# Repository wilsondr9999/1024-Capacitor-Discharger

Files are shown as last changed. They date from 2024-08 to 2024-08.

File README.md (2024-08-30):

# Capacitor Discharger

This project is a passive (unpowered) capacitor discharger that can safely discharge capacitors up to 450V and 1000 uF.  It assists the operator in quickly discharging the capacitor and providing visual feedback of the discharging process and its completion.

## Overview

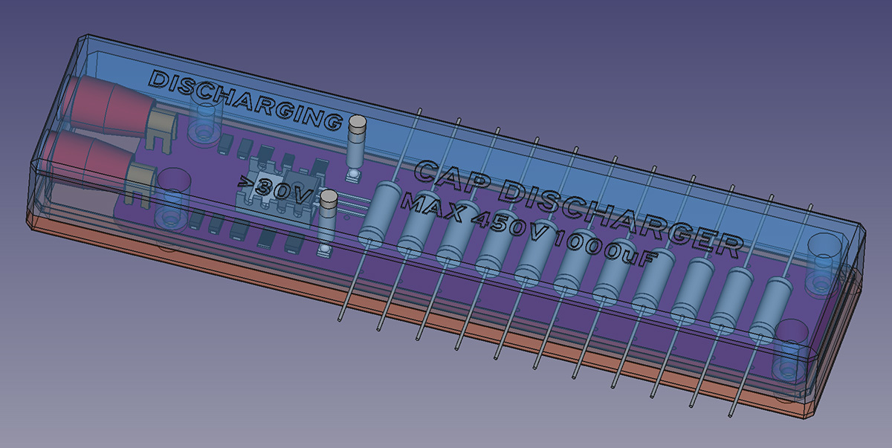
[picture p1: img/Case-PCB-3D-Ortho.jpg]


The capacitor discharger is a handheld unit with 2 LEDs for indication, and two standard shrouded test lead ports on one end.  It's purpose is to allow safe discharge of a capacitor that is in-circuit prior to working on that circuit.  Capacitors can hold a charge, sometimes for a long period of time, and in some circuits the amount of energy they can hold is dangerous, even potentially lethal.

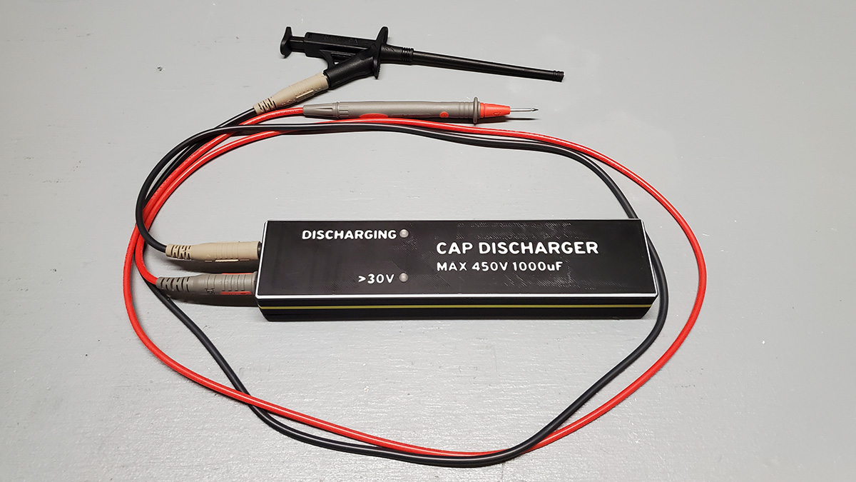
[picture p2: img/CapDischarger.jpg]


This unit allows the operator to touch two test leads to the capacitor terminals, and the unit will allow the capacitor to discharge at a constant rate of 125 mA.  This is sufficient current to discharge the largest capacitor that is recommended to be discharged with this unit (a capacitor rated up to 450V, and up to 1000 uF of capacitance) within about 15 seconds.

## Principle of Operation

The unit is a passive device, i.e. it is not powered and no batteries or power source is needed.  The energy in the capacitor is used to light the indicator LEDs during the discharge.

A fixed resistance bank is used to allow the capacitor to discharge at a constant current of 125 mA.  The capacitor's energy is dumped into 11 resistors rated at 5W each.

One LED (yellow) lights as the capacitor is discharging.  This LED will remain lit until the capacitor has no more energy (usually when it's voltage is less than 2V).

The other LED (red) lights if the capacitor voltage is above 30V.  This LED will extinguish when the capacitor has discharged to less than 30V, indicating that the capacitor would be safe to touch.  An IGBT transistor is used in a specific configuration to drive the >30V LED.

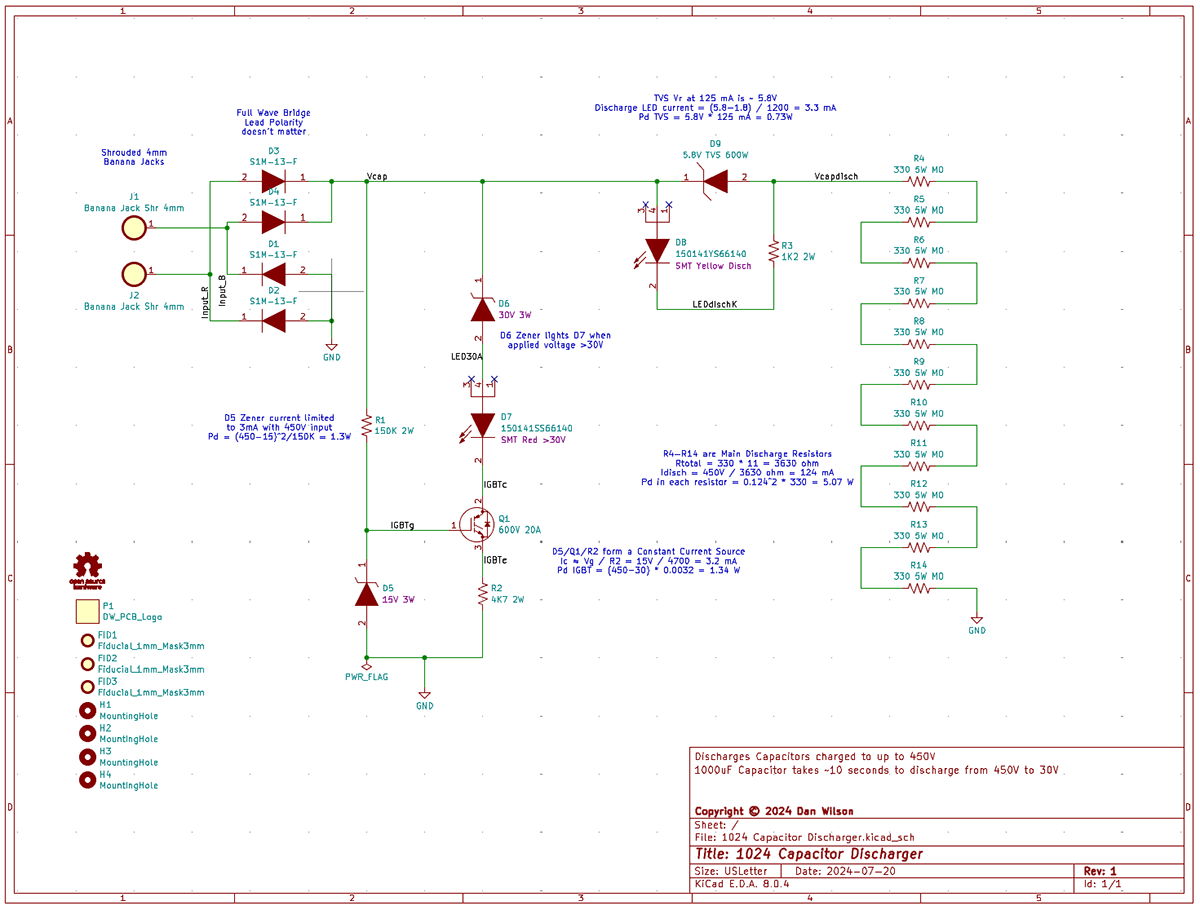
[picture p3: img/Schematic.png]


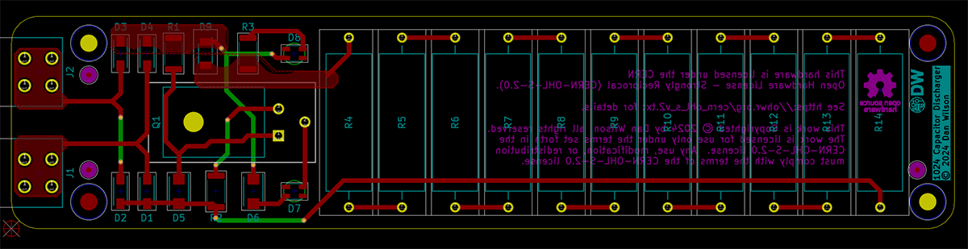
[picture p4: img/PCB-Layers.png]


## Instructions for Use

Attach two test leads to the 4mm jacks on the end of the unit.  The unit does not have a polarity restriction, and can discharge capacitors in both orientations.  It is recommended that your test leads are of a type that are rated for at least the working voltage of the capacitor you intend to discharge.  If the voltage is greater than 50V, it is recommended to use high voltage test leads with a category rating of at least CAT I / 600V.

For voltages greater than 50V, use appropriate personal protective equipment (PPE), including electrical safety gloves and safety glasses.

With appropriate personal safety equipment in place, touch the test leads to the capacitor leads in either orientation.  The unit will begin discharging the capacitor, and you will see the yellow discharging LED light up.  The red >30V LED will also light if the capacitor voltage is currently greater than 30V.

Keep the test leads connected to the capacitor until the >30V LED light extinguished.  Once the >30V LED light is extinguished, the capacitor is safe to work with.  If the work requires as close to zero charge in the capacitor as possible, continue holding the test leads connected to the capacitor until the discharge LED light is dim or extinguished.

## Assembly

Gerber files are available in the [1024 Capacitor Discharger](KiCAD%20Project%20-%20Discharger/Fabrication%20Exports/1024%20Capacitor%20Discharger.zip) folder.  The [1024 Capacitor Discharger](KiCAD%20Project%20-%20Discharger/Fabrication%20Exports/1024%20Capacitor%20Discharger.zip) file is a pre-compressed archive that is ready to upload to Oshpark.

All parts needed are listed in the [BOM](KiCAD%20Project%20-%20Discharger/BOM/BOM%201024%20Capacitor%20Discharger.csv) CSV file.

If you want to use a solder stencil for reflow of the SMD components, Osh Stencils can produce this stencil from the [1024 Capacitor Discharger-F_Paste](KiCAD%20Project%20-%20Discharger/Fabrication%20Exports/1024%20Capacitor%20Discharger-F_Paste.gbr) Gerber file.  Select a Stainless Steel 4 mil stencil with a border size of 0.75 inches.  The Solder Stencil Jig is designed to fit this stencil.

Use the [SSJv2 1024 Capacitor Discharger](FreeCAD%20Project/Solder%20Stencil%20Jig%20V2/SSJv2%201024%20Capacitor%20Discharger.stl) file to print the solder stencil jig.  A .3mf file is included if you use PrusaSlicer.  Otherwise use the .stl file with the following settings:

- 0.2 mm layer height
- 3 perimeters
- 4 solid layers on bottom
- 5 solid layers on top
- 20% infill
- No supports required

Solder the SMD components onto the PCB using the stencil + solder paste + reflow, or hand solder them.

Solder the THT components onto the PCB by hand.  Be careful when bending the IGBT legs, they need to be accurate because the hole in the TO-220 case must align with the heat sink and the hole in the PCB.  It is recommended to solder the 4mm PCB-mount Banana jacks while the board is fitted into the case top.  This will ensure that the Banana jacks are perfectly aligned and will not impede the fitting of the PCB in the case.

There is a [ResistorBender](FreeCAD%20Project/1024%20Capacitor%20Discharger%20Case/ResistorBender.stl) file in the 1024 Capacitor Discharge Case directory, this can be optionally printed to properly and uniformly bend the resistor legs to fit the PCB.

When assembling the IGBT heat sink, the stackup should be (from the top down):

- M3x8 button-head screw
- Screw insulator
- TO-220 IGBT
- Thermal grease/compound
- Mica insulator sheet from the TO-220 mounting kit listed in the BOM
- Thermal grease/compound
- Aluminum heat sink
- PCB
- (Back of PCB) Flat Washer
- (Back of PCB) M3 hex nut

The screw that is supplied with the TO-220 mounting kit is too long to fit properly in the printed case.  Replace this screw and nut with a button head M3x8 screw, and use the flat washer and an M3 hex nut on the back of the PCB.  Do not use the lock washer.  This should clear the printed case when assembled.

The Mica insulator sheet may be slightly too large to fit inside the aluminum heat sink.  It can be trimmed with scissors.

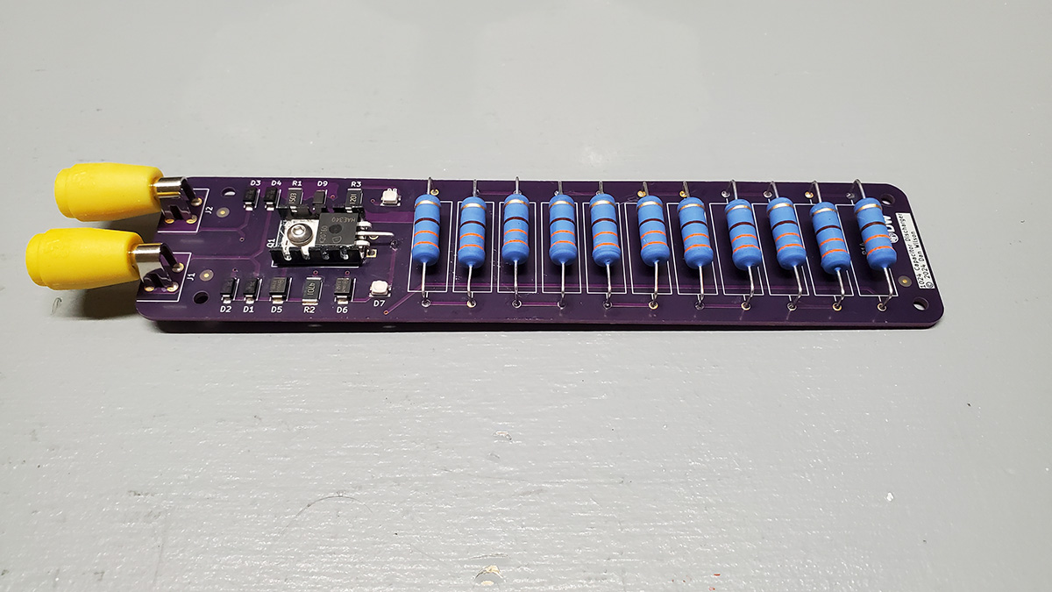
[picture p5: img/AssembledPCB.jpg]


Use the [CaseBottom](FreeCAD%20Project/1024%20Capacitor%20Discharger%20Case/CaseBottom.stl) and [CaseTop](FreeCAD%20Project/1024%20Capacitor%20Discharger%20Case/CaseTop.stl) files to print the case, using the same settings as the solder stencil jig.  Use a soldering iron to insert 4 Heat-Set Inserts into the case top.  The Heat-Set Inserts should be an M3 x 6mm size.  The screws used to assembly the case should be an M3x12 with a hex cap head.

Assemble the case halves together with the PCB inside, and insert the 4 hex cap M3x12 screws and tighten.

## License

This project is licensed under two restrictive licenses:

The hardware design is licensed under the CERN Open Hardware Licence Version 2 - Strongly Reciprocal.

The documentation, images, and instructions are licensed under the Creative Commons Attribution-ShareAlike 4.0 International Public License.

As stated by the licenses, all uses of this project require attribution and require open-source release under the same licenses.

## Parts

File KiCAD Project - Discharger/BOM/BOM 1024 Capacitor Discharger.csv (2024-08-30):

Reference | Value | Datasheet | Footprint | Qty | DNP | Height | Manufacturer_Name | Manufacturer_Part_Number | Mouser Part Number | Mouser Price/Stock | Description
D1,D2,D3,D4 | S1M-13-F | https://www.mouser.com/datasheet/2/115/DIOD_S_A0007810797_1-2542915.pdf | DW_Semiconductors:[D] Diodes Inc S1M-F | 4 |  | 2.4 | Diodes Incorporated | S1M-13-F | 621-S1M-F | https://www.mouser.com/ProductDetail/Diodes-Incorporated/S1M-13-F?qs=Ql%252B1sS8nYriQkfvrdt%252Befw%3D%3D | Diode Standard 1A 1000V SMA Diodes Inc S1M-13-F, SMT Diode, 1000V 1A, 3us, 2-Pin DO-214AC
D5 | 1SMB5929BT3G | https://www.mouser.com/datasheet/2/308/1SMB5913BT3_D-2309637.pdf | DW_Semiconductors:[D] OnSemi Zener DIOM5436X247N | 1 |  | 2.47 | onsemi | 1SMB5929BT3G | 863-1SMB5929BT3G | https://www.mouser.com/ProductDetail/onsemi/1SMB5929BT3G?qs=vLkC5FC1VN%2FFUr7OS2Q1Aw%3D%3D | 15V 3W
D6 | 1SMB5936BT3G | https://www.mouser.com/datasheet/2/308/1SMB5913BT3_D-2309637.pdf | DW_Semiconductors:[D] OnSemi Zener DIOM5436X247N | 1 |  | 2.47 | onsemi | 1SMB5936BT3G | 863-1SMB5936BT3G | https://www.mouser.com/ProductDetail/onsemi/1SMB5936BT3G?qs=vLkC5FC1VN%252BcVJc0CAOIaw%3D%3D | 30V 3W
D7 | 150141SS66140 | https://www.we-online.com/components/products/datasheet/150141SS66140.pdf | DW_Optoelectronics:[D] Wurth Elektronik 150141SS66140 | 1 |  | 3.27 | Wurth Elektronik | 150141SS66140 | 710-150141SS66140 | https://www.mouser.com/ProductDetail/Wurth-Elektronik/150141SS66140 | SMT Red >30V
D8 | 150141YS66140 | https://www.we-online.com/components/products/datasheet/150141YS66140.pdf | DW_Optoelectronics:[D] Wurth Elektronik 150141SS66140 | 1 |  | 3.27 | Wurth Elektronik | 150141YS66140 | 710-150141YS66140 | https://www.mouser.com/ProductDetail/Wurth-Elektronik/150141YS66140 | SMT Yellow Disch
D9 | 5.8V TVS 600W | https://assets.nexperia.com/documents/data-sheet/PTVSXP1UTP_SER.pdf | DW_Semiconductors:[D] Nexperia TVS UniDir PMEG3050EP115 | 1 |  | 1 | Nexperia | PTVS3V3P1UTP,115 | 771-PTVS3V3P1UTP,115 | https://www.mouser.com/ProductDetail/Nexperia/PTVS3V3P1UTP115?qs=zHGtguZFFhJcijDs1k8WAg%3D%3D | PTVSxP1UTP series - High-temperature 600 W Transient Voltage Suppressor 8V Clamp
J1,J2 | Banana Jack Shr 4mm | https://www.mouser.com/datasheet/2/701/P315100_rJ_2c_4mm_Sheathed_Jack_2c_H_V_PCB-3049282.pdf | DW_Connectors:[J] CalTestElec CT3151SP-X | 2 |  | 13.1 | Cal Test Electronics | CT3151SP-X | 510-CT3151SP-4 | https://www.mouser.com/ProductDetail/Cal-Test/CT3151SP-4?qs=vgjKjNJexTiUhiQE6j1VnQ%3D%3D | 4mm Sheath Banana Jacks (Sockets), PCB Mount
Q1 | 600V 20A | https://www.mouser.com/datasheet/2/196/Infineon_IKP20N60T_DS_v02_08_EN-1226893.pdf | DW_Semiconductors:[Q] Infineon IKP20N60T IGBT with ATS-PCB1069 Heat Sink | 1 |  | 4.6 | Infineon | IKP20N60T | 726-IKP20N60T | https://www.mouser.com/ProductDetail/Infineon-Technologies/IKP20N60T?qs=MGskQgfwDzvyssErInthQw%3D%3D | Infineon IKP20N60T, IGBT Transistor, 20 A 600 V, TO-220-3
R1 | 150K 2W | https://www.mouser.com/datasheet/2/418/9/ENG_DS_9_1773463_9_B-3355381.pdf | Resistor_SMD:R_2512_6332Metric | 1 |  | 0.65 | TE Connectivity | CRGP2512F150K | 279-CRGP2512F150K | https://www.mouser.com/ProductDetail/TE-Connectivity-Holsworthy/CRGP2512F150K?qs=wUXugUrL1qyVym0XbWLrww%3D%3D | Resistor SMD 2512 150K 2W 500V
R2 | 4K7 2W | https://www.mouser.com/datasheet/2/418/9/ENG_DS_9_1773463_9_B-3355381.pdf | Resistor_SMD:R_2512_6332Metric | 1 |  | 0.65 | TE Connectivity | CRGP2512F4K7 | 279-CRGP2512F4K7 | https://www.mouser.com/ProductDetail/TE-Connectivity-Holsworthy/CRGP2512F4K7?qs=wUXugUrL1qyjkhd5xm375g%3D%3D | Resistor SMD 2512 4K7 2W 500V
R3 | 1K2 2W | https://www.mouser.com/datasheet/2/418/9/ENG_DS_9_1773463_9_B-3355381.pdf | Resistor_SMD:R_2512_6332Metric | 1 |  | 0.65 | TE Connectivity | CRGP2512F1K2 | 279-CRGP2512F1K2 | https://www.mouser.com/ProductDetail/TE-Connectivity-Holsworthy/CRGP2512F1K2?qs=wUXugUrL1qxu8QkZf2oZow%3D%3D | Resistor SMD 2512 1K2 2W 500V
R4,R5,R6,R7,R8,R9,R10,R11,R12,R13,R14 | 330 5W MO | https://www.mouser.com/datasheet/2/418/9/ENG_DS_1773271_J-1533579.pdf | DW_Passives:[R] TE Connectivity MO Res 5W | 11 |  | 12 | TE Connectivity | ROX5SSJ330R | 279-ROX5SSJ330R | https://www.mouser.com/ProductDetail/TE-Connectivity-Holsworthy/ROX5SSJ330R?qs=gZXFycFWdAPeoyzsPxupwQ%3D%3D | Metal Oxide Film Resistor, 5W, 750V
 |  | https://www.mouser.com/datasheet/2/596/advanced_thermal_solutions_09052018_Stamped_Heat_S-1480352.pdf |  | 1 |  | 6.35 | Advanced Thermal Solutions | ATS-PCB1069 | 984-ATS-PCB1069 | https://www.mouser.com/ProductDetail/984-ATS-PCB1069 | IGBT Heat Sink
 |  | https://www.mouser.com/datasheet/2/2/AAVT_S_A0001435767_1-2900880.pdf |  | 1 |  | 0.5 | Aavid | 4880MG | 532-4880M | https://www.mouser.com/ProductDetail/532-4880M | TO-220 Insulating Mount Kit
 |  | https://www.mouser.com/datasheet/2/109/Dialight_12192017_Panel%20Mount%205mm%20Lightpipe-1272673.pdf |  | 2 |  | 12.5 | Dialight | 51513530500F | 645-51513530500F | https://www.mouser.com/ProductDetail/645-51513530500F | LED Light Pipes

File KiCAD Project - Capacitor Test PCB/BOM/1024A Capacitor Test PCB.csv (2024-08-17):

Reference | Value | Datasheet | Footprint | Qty | DNP | Height | Manufacturer_Name | Manufacturer_Part_Number | Mouser Part Number | Mouser Price/Stock | Description
BR1 | 800V 4A | https://www.vishay.com/docs/98472/gblxxe.pdf | DW_Semiconductors:[BR] Vishay 800V 4A Bridge Rectifier GBL08EE3P | 1 |  | 13.2 | Vishay | GBL08E-E3/P | 78-GBL08E-E3/P | https://www.mouser.com/ProductDetail/Vishay-General-Semiconductor/GBL08E-E3-P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 | Bridge Rectifier Single Phase Standard 800 V Through Hole GBL
C1 | 47n X2 310V | https://content.kemet.com/datasheets/KEM_F3001_F861_X2_310.pdf | DW_Passives:[C] Kemet Film Cap 47n 310V X2 | 1 |  | 12 | Kemet | F861KM473M310C | 80-F861KM473M310C | https://www.mouser.com/ProductDetail/KEMET/F861KM473M310C?qs=8sjaHP9aaypF0AhqggDZQw%3D%3D | 47n 310V X2
C2 | 1000u 450V | https://content.kemet.com/datasheets/KEM_A4081_ALC70.pdf | DW_Passives:[C] Kemet ALC70C102EH450 Al Elec Cap 450V 1000uF | 1 |  | 60 | Kemet | ALC70C102EH450 | 80-ALC70C102EH450 | https://www.mouser.com/ProductDetail/KEMET/ALC70C102EH450 | 450V 1000uF Aluminum Electrolytic Cap
F1 | 2.5A 250V | https://www.mouser.com/datasheet/2/240/media-3320444.pdf | DW_CircuitProtection:[F] Littelfuse TE5-372 | 1 |  | 8 | Littelfuse | 39212500440 | 576-39212500440 | https://www.mouser.com/ProductDetail/Littelfuse/39212500440?qs=c4XZgm4o%252BwK5%252B4Ac9n6Y%252BA%3D%3D | 1A 250V AC DC Fuse Board Mount (Cartridge Style Excluded) Through Hole Radial, Rectangle, Vertical
J1 | JST-VH 3P Side Entry | https://www.jst-mfg.com/product/pdf/eng/eVH.pdf | DW_Connectors:[J] JST-VN 3P Side Entry | 1 |  | 10.5 | JST (JAPAN SOLDERLESS TERMINALS) | B3PS-VH |  |  | JST VH Series, 3.96mm Pitch 3 Way 1 Row Right Angle PCB Header, Solder Termination, 10A
RT1 | 20ohm 5A 125J | https://www.mouser.com/datasheet/2/600/SL2220005-276636.pdf | DW_CircuitProtection:[RT] Ametherm SL22 20005 ICL | 1 |  | 31.35 | AMETHERM | SL22 20005 | 995-SL22-20005 | https://www.mouser.com/ProductDetail/Ametherm/SL22-20005?qs=PVyXUKBeRH3ShXanrNm8zg%3D%3D | Inrush Current Limiters 22mm 20ohms 5A
RV1 | 275V 140J | https://www.mouser.com/datasheet/2/240/media-3323714.pdf | DW_CircuitProtection:[RV] Littelfuse MOV V275LA40AP | 1 |  | 26.5 | LITTELFUSE | V275LA40AP | 576-V275LA40AP | https://www.mouser.com/ProductDetail/Littelfuse/V275LA40AP?qs=Mty3Fo4ApVihzZDsMCd%252BxQ%3D%3D | Littelfuse, LA Metal Oxide Varistor 900pF 100A, Clamping 710V, Varistor 473V
TP1,TP2 | TP THT Red | https://www.mouser.com/datasheet/2/215/5005_5009-741322.pdf | DW_Connectors:[TP] Keystone Elec TP THT 5005 Red | 2 |  | 5.6 | Keystone Electronics | 5005 | 534-5005 | https://www.mouser.com/ProductDetail/Keystone-Electronics/5005?qs=q0tsjPZWdm%252BiIco20yB3BQ%3D%3D | Test Point, PC, Snap in Mounting, Compact, Red Base
TP3,TP4 | TP THT Black | https://www.mouser.com/datasheet/2/215/5005_5009-743680.pdf | DW_Connectors:[TP] Keystone Elec TP THT 5006 Black | 2 |  | 5.6 | Keystone Electronics | 5006 | 534-5006 | https://www.mouser.com/ProductDetail/Keystone-Electronics/5006?qs=q0tsjPZWdm99DN5QVOwb8g%3D%3D | Test Point, PC, Snap in Mounting, Compact, Black Base

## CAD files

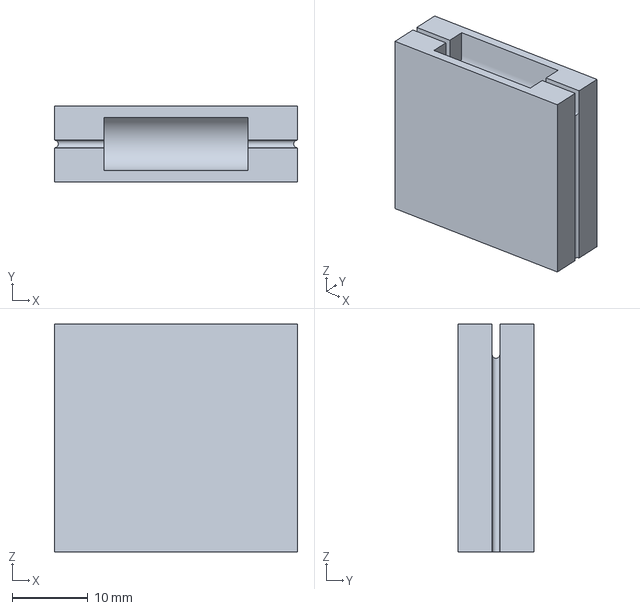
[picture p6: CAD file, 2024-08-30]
FreeCAD Project/1024 Capacitor Discharger Case/ResistorBender.3mf
32.0 x 10.0 x 30.0 mm

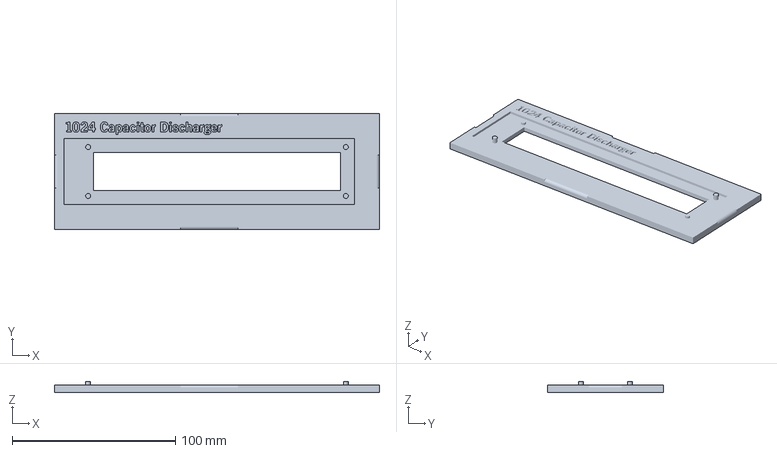
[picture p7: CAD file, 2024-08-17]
FreeCAD Project/Solder Stencil Jig V2/SSJv2 1024 Capacitor Discharger.3mf
199.3 x 71.3 x 6.60 mm

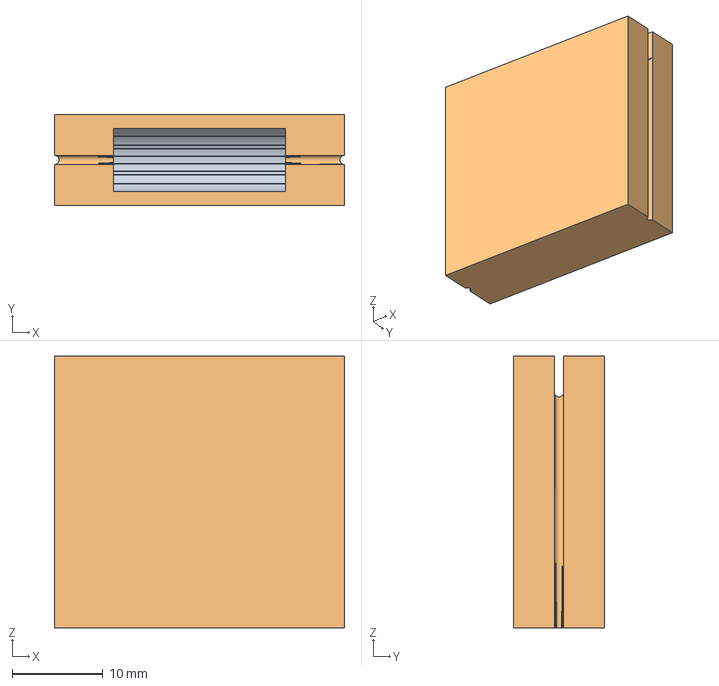
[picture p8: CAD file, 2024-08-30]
FreeCAD Project/1024 Capacitor Discharger Case/1024 Capacitor Discharger Case.FCStd
32.0 x 10.0 x 30.0 mm
Body-ResistorBender
Body-ResistorBender (Meshed)

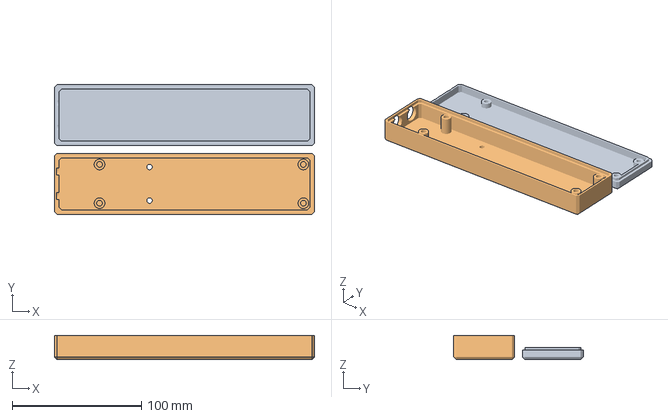
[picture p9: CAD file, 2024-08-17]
FreeCAD Project/1024 Capacitor Discharger Case/Case.3mf
201.5 x 100.4 x 18.8 mm
CaseBottom.stl
CaseTop.stl

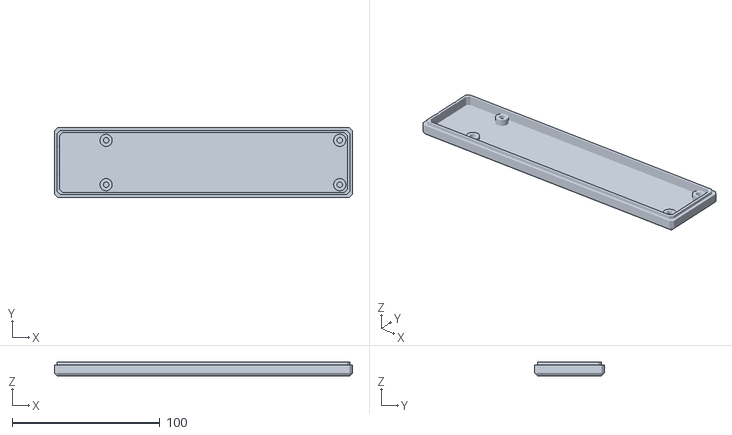
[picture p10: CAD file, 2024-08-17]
FreeCAD Project/1024 Capacitor Discharger Case/CaseBottom.stl
201.5 x 47.2 x 9.53

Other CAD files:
FreeCAD Project/1024 Capacitor Discharger Case/ResistorBender.stl

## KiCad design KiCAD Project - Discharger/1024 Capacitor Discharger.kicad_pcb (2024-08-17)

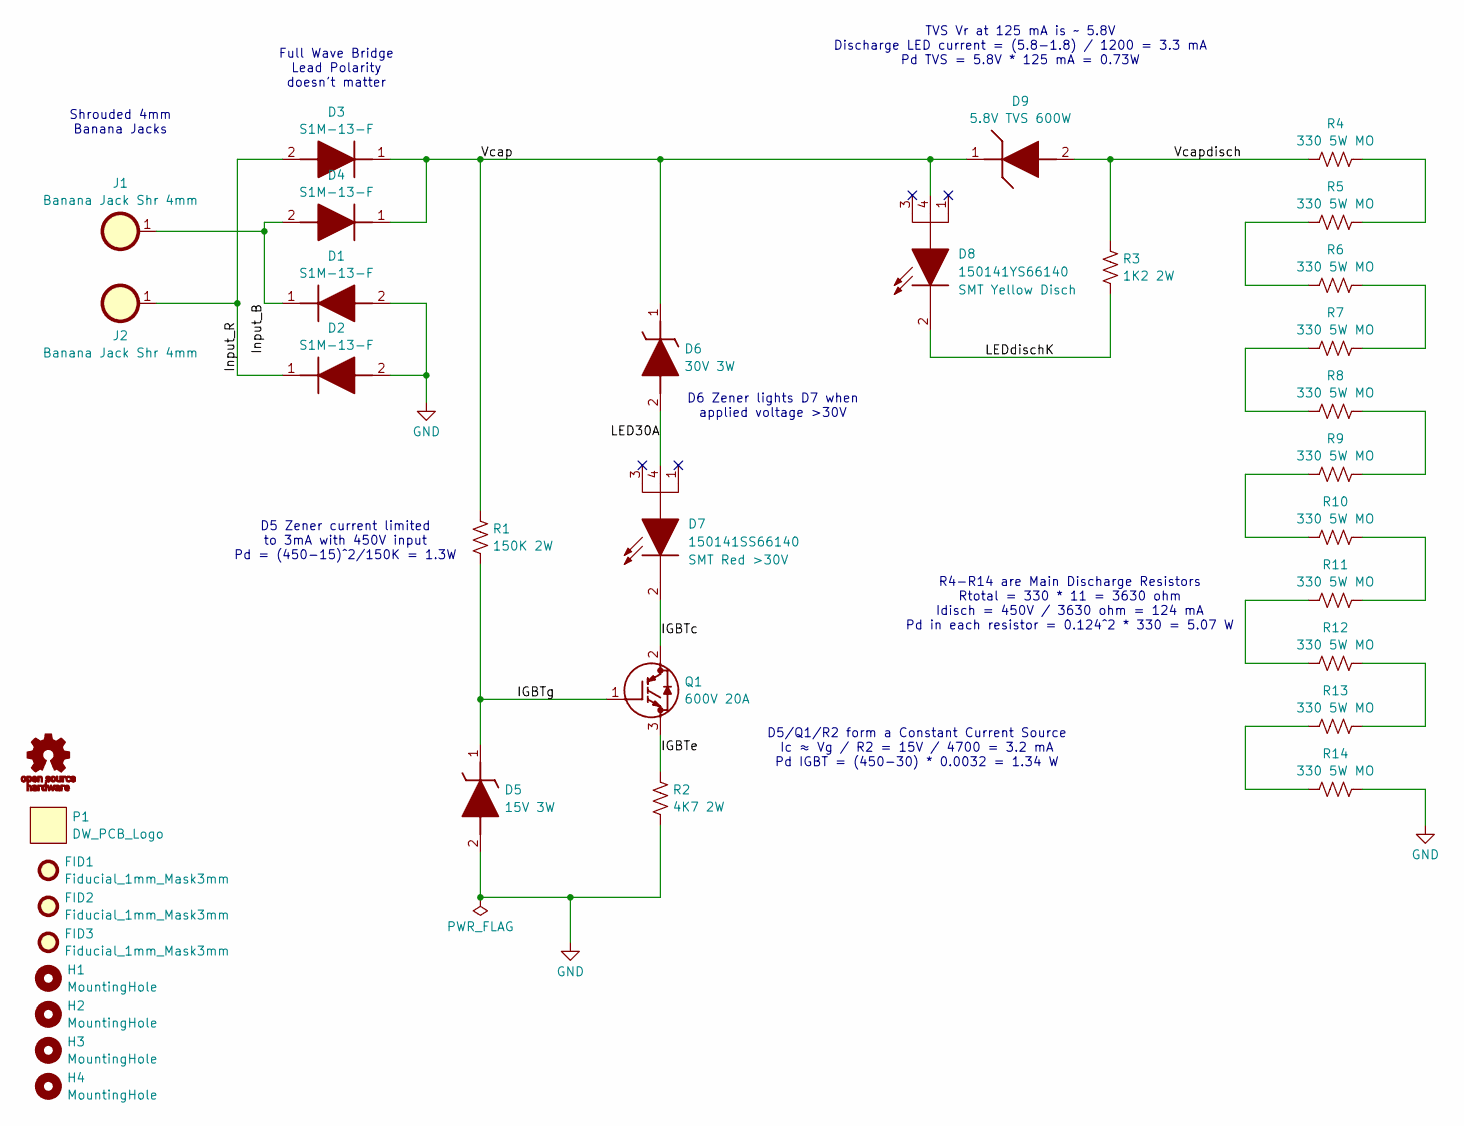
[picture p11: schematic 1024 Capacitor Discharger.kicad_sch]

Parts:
D1, D2, D3, D4: S1M-13-F; [D] Diodes Inc S1M-F; Mouser Part Number 621-S1M-F
D5: 1SMB5929BT3G; [D] OnSemi Zener DIOM5436X247N; Mouser Part Number 863-1SMB5929BT3G
D6: 1SMB5936BT3G; [D] OnSemi Zener DIOM5436X247N; Mouser Part Number 863-1SMB5936BT3G
D7: 150141SS66140; [D] Wurth Elektronik 150141SS66140; Mouser Part Number 710-150141SS66140
D8: 150141YS66140; [D] Wurth Elektronik 150141SS66140; Mouser Part Number 710-150141YS66140
D9: 5.8V TVS 600W; [D] Nexperia TVS UniDir PMEG3050EP115; Mouser Part Number 771-PTVS3V3P1UTP,115
FID1, FID2, FID3: Fiducial_1mm_Mask3mm
G1: OSHW_Logo
H1, H2, H3, H4: MountingHole; MountingHole_3.2mm_M3
J1, J2: Banana Jack Shr 4mm; [J] CalTestElec CT3151SP-X; Manufacturer_Part_Number CT3151SP-X; Mouser Part Number 510-CT3151SP-4
P1: DW_PCB_Logo
Q1: 600V 20A; [Q] Infineon IKP20N60T IGBT with ATS-PCB1069 Heat Sink; Mouser Part Number 726-IKP20N60T
R1: 150K 2W; R_2512_6332Metric; Manufacturer_Part_Number CRGP2512F150K; Mouser Part Number 279-CRGP2512F150K
R2: 4K7 2W; R_2512_6332Metric; Manufacturer_Part_Number CRGP2512F4K7; Mouser Part Number 279-CRGP2512F4K7
R3: 1K2 2W; R_2512_6332Metric; Manufacturer_Part_Number CRGP2512F1K2; Mouser Part Number 279-CRGP2512F1K2
R4, R5, R6, R7, R8, R9, R10, R11, R12, R13, R14: 330 5W MO; [R] TE Connectivity MO Res 5W; Manufacturer_Part_Number ROX5SSJ330R; Mouser Part Number 279-ROX5SSJ330R

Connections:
/IGBTc: D7.2 (K), Q1.2 (C)
/IGBTe: Q1.3 (E), R2.1
/IGBTg: D5.1 (K), Q1.1 (G), R1.2
/Input_B: D1.1 (K), D4.2 (A), J1.1
/Input_R: D2.1 (K), D3.2 (A), J2.1
/LED30A: D6.2 (A), D7.4 (A2)
/LEDdischK: D8.2 (K), R3.2
/Vcap: D3.1 (K), D4.1 (K), D6.1 (K), D8.4 (A2), D9.1 (K), R1.1
/Vcapdisch: D9.2 (A), R3.1, R4.1
GND: D1.2 (A), D2.2 (A), D5.2 (A), R2.2, R14.2
unnamed: R4.2, R5.2
unnamed: R5.1, R6.1
unnamed: R6.2, R7.2
unnamed: R7.1, R8.1
unnamed: R8.2, R9.2
unnamed: R9.1, R10.1
unnamed: R10.2, R11.2
unnamed: R11.1, R12.1
unnamed: R12.2, R13.2
unnamed: R13.1, R14.1

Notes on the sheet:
Full Wave Bridge Lead Polarity doesn't matter
R4-R14 are Main Discharge Resistors Rtotal = 330 * 11 = 3630 ohm Idisch = 450V / 3630 ohm = 124 mA Pd in each resistor = 0.124^2 * 330 = 5.07 W
TVS Vr at 125 mA is ~ 5.8V Discharge LED current = (5.8-1.8) / 1200 = 3.3 mA Pd TVS = 5.8V * 125 mA = 0.73W
D5/Q1/R2 form a Constant Current Source Ic ≈ Vg / R2 = 15V / 4700 = 3.2 mA Pd IGBT = (450-30) * 0.0032 = 1.34 W
Shrouded 4mm Banana Jacks
D6 Zener lights D7 when applied voltage >30V
D5 Zener current limited to 3mA with 450V input Pd = (450-15)^2/150K = 1.3W

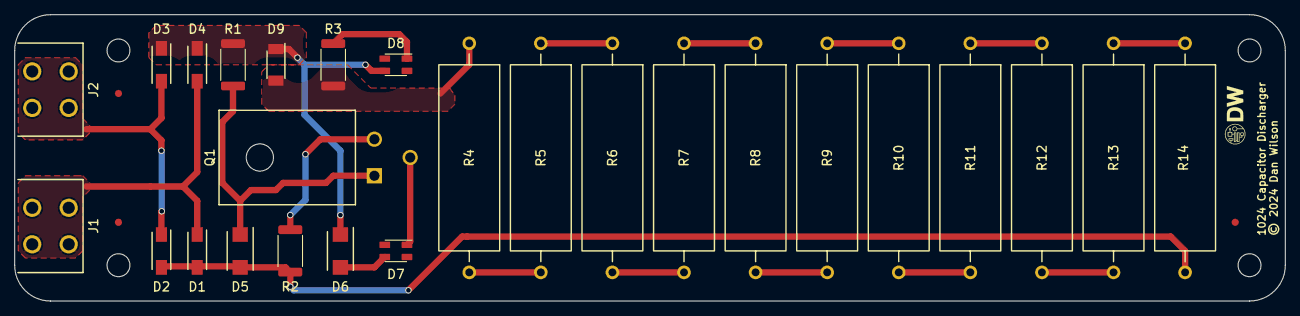
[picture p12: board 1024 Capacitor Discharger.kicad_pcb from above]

Board: 2 copper layers, 177.5 x 40.0 mm, 35 parts (1 on the bottom side), 20 nets.

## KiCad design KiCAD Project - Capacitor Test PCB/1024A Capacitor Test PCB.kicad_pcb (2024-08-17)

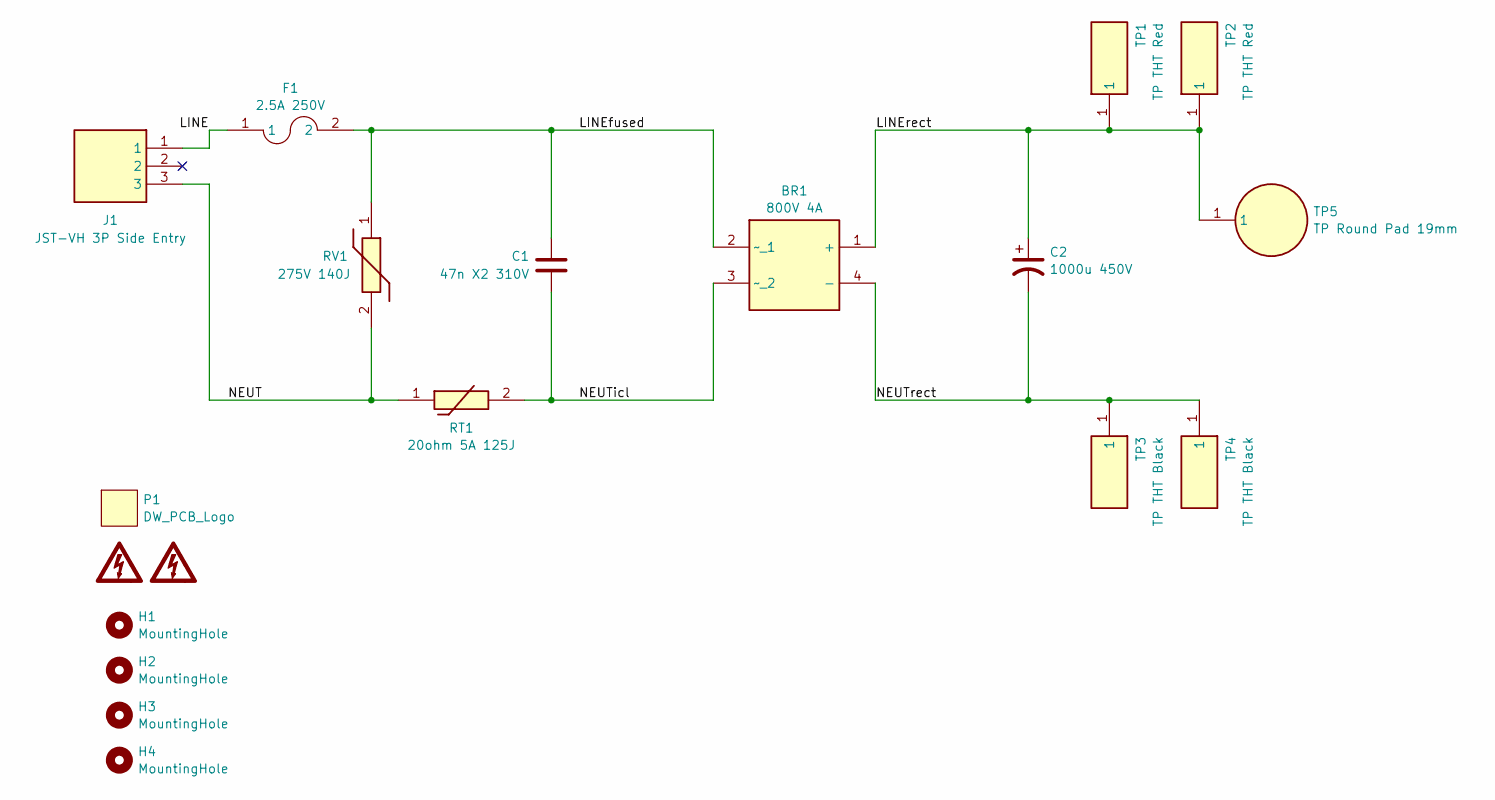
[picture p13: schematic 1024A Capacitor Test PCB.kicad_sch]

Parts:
BR1: 800V 4A; [BR] Vishay 800V 4A Bridge Rectifier GBL08EE3P; Mouser Part Number 78-GBL08E-E3/P
C1: 47n X2 310V; [C] Kemet Film Cap 47n 310V X2; Manufacturer_Part_Number F861KM473M310C; Mouser Part Number 80-F861KM473M310C
C2: 1000u 450V; [C] Kemet ALC70C102EH450 Al Elec Cap 450V 1000uF; Manufacturer_Part_Number ALC70C102EH450; Mouser Part Number 80-ALC70C102EH450
F1: 2.5A 250V; [F] Littelfuse TE5-372; Mouser Part Number 576-39212500440
G1, G2: High_Voltage_6.5mm
H1, H2, H3, H4: MountingHole; MountingHole_3.2mm_M3
J1: JST-VH 3P Side Entry; [J] JST-VN 3P Side Entry; Manufacturer_Part_Number B3PS-VH; Digikey Part Number 455-B3PS-VH-ND
P1: DW_PCB_Logo
RT1: 20ohm 5A 125J; [RT] Ametherm SL22 20005 ICL; Mouser Part Number 995-SL22-20005
RV1: 275V 140J; [RV] Littelfuse MOV V275LA40AP; Mouser Part Number 576-V275LA40AP
TP1, TP2: TP THT Red; [TP] Keystone Elec TP THT 5005 Red; Mouser Part Number 534-5005
TP3, TP4: TP THT Black; [TP] Keystone Elec TP THT 5006 Black; Mouser Part Number 534-5006
TP5: TP Round Pad 19mm; [TP] Round Pad for Test Lead

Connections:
/LINE: F1.1, J1.1
/LINEfused: BR1.2 (~_1), C1.1, F1.2, RV1.1
/LINErect: BR1.1 (+), C2.1, TP1.1, TP2.1, TP5.1
/NEUT: J1.3, RT1.1, RV1.2
/NEUTicl: BR1.3 (~_2), C1.2, RT1.2
/NEUTrect: BR1.4 (-), C2.2, TP3.1, TP4.1

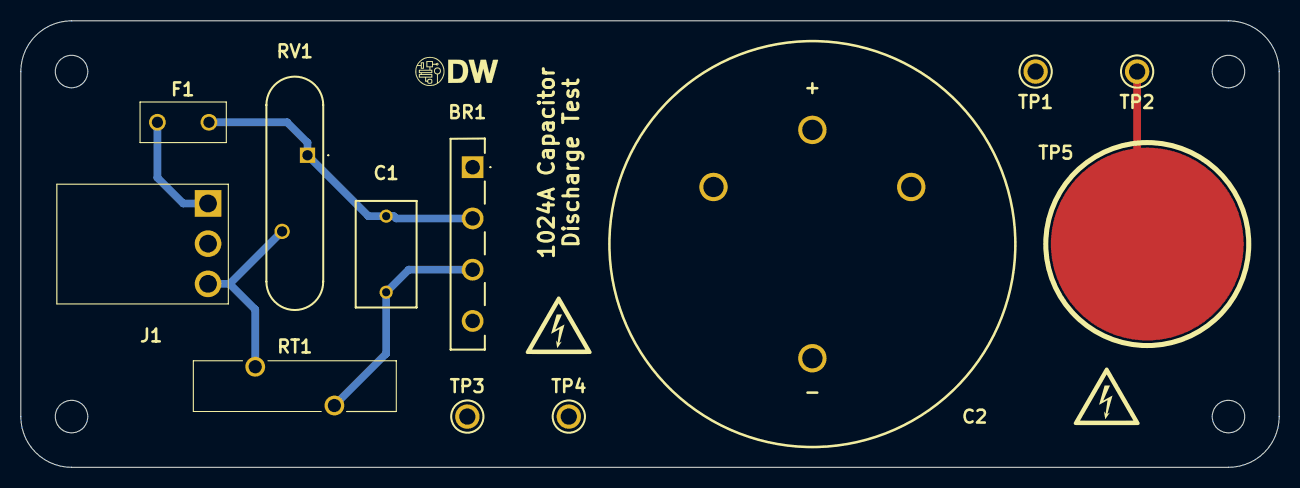
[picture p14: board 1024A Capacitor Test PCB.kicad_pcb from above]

Board: 2 copper layers, 124.0 x 44.0 mm, 19 parts (0 on the bottom side), 6 nets.

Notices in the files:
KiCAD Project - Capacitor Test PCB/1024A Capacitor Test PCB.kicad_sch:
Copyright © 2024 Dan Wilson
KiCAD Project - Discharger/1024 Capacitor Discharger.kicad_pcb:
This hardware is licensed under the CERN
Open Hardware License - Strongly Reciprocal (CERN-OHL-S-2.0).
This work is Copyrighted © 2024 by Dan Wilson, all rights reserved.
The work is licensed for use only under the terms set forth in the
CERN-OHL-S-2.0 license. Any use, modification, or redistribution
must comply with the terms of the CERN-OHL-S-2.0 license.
